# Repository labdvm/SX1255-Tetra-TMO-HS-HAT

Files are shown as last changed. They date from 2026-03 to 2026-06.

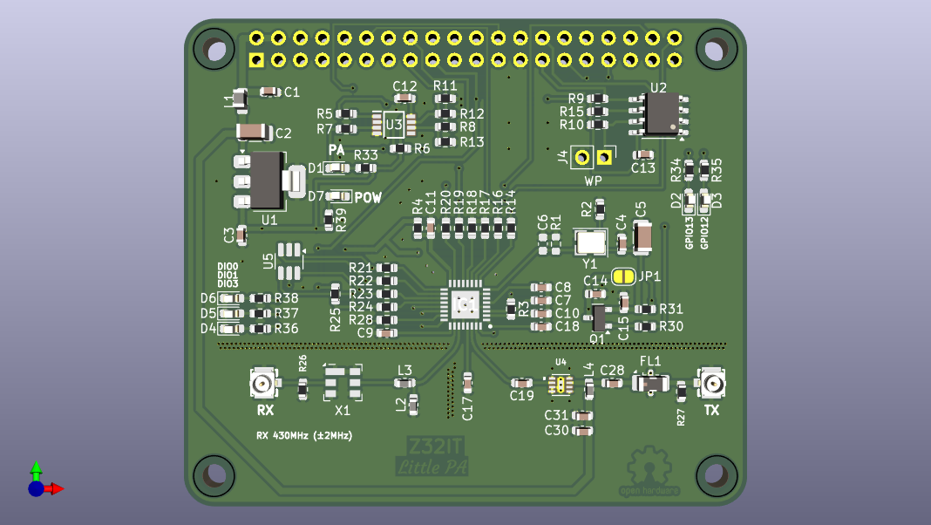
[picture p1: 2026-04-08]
HAT with PA/HAT with PA.png

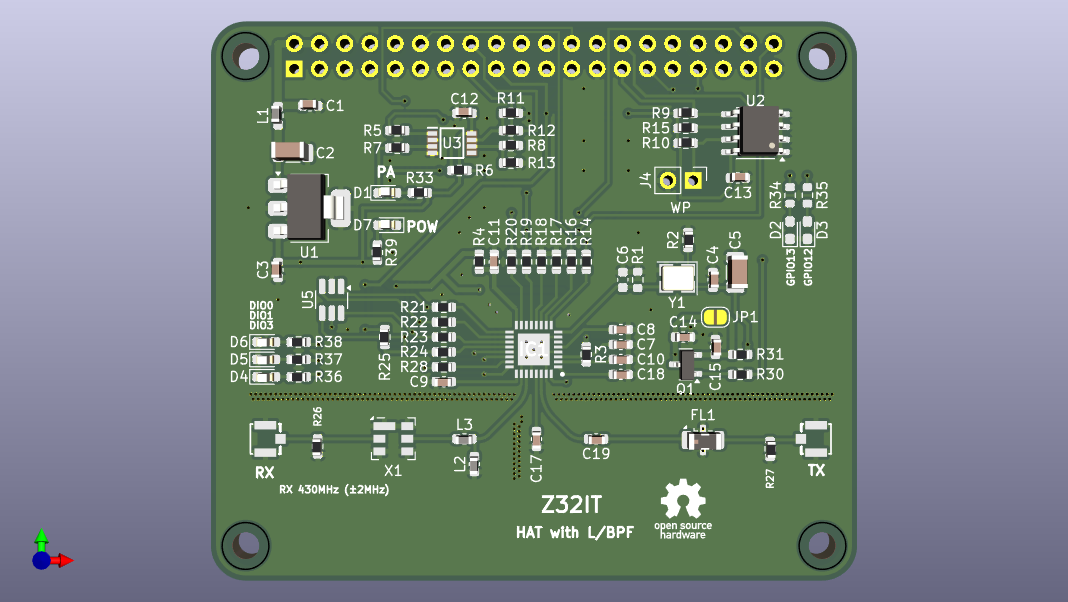
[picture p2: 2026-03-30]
HAT without PA/HAT without PA.png

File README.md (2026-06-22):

# SX1255--HAT's

# Little PA HAT you can order from here:
- <a href="https://www.pcbway.com/project/shareproject/SX1255_HAT_Little_PA_16c1f7b7.html">PCB from PCBWay</a>

This is modified SXceiver, thanks to Tatu Peltola for shared schematic.
# Two versions of HAT's: HAT with (LPF_TX, BPF_RX filters and PA) and HAT with (LPF_TX, BPF_RX filters without PA) and added SPI line protection IC. The first HAT also is known as "Little PA".
# The PA (TQP3M9036) can amplify up to ~25dBm @ (70cm-band) 
# I can make Custom design too. (pclab.mk@gmail.com)
# RPi 4/5, fast-write micro-sd card or upgraded with M.2 nvme drive.
# The eeprom is for HW-ID " https://github.com/tejeez/sxxcvr/blob/main/dts/README.md ".
# For Tetra-TMO Base Station this is the installing procedures, " https://github.com/MidnightBlueLabs/tetra-bluestation-docs/wiki ".
# BlueStation, https://github.com/MidnightBlueLabs/tetra-bluestation
# BlueStation Tetra TMO configurator " https://bluestation.russel053.com/ "
# FlowStation, https://github.com/razvanzeces/flowstation
# Nexus-BS, https://github.com/invictus737/nexus-bs

Install FlowStation ---for sxceiver---
# 1. Install Trixie 64bit-LITE
2. Install lib's:
# sudo apt update
# sudo apt install git make g++ cmake
# sudo apt install libsoapysdr-dev
# sudo apt install soapysdr-tools
# sudo apt install libasound2-dev
# sudo apt install clang llvm-dev libclang-dev

3. Install Rust:
# curl https://sh.rustup.rs -sSf | sh

4. RPi-setup:
"enable SPI and I2C"
# sudo raspi-config > Interface Options > "enable and reboot the rpi"
# sudo nano /boot/firmware/config.txt
"add"
# dtparam=i2c_vc=on
"Reboot the Rpi"

5. Install SoapySX:
# cd
# git clone "https://github.com/tejeez/sxxcvr.git"
# cd sxxcvr/SoapySX
# mkdir build
# cd build
# cmake ..
# make
# sudo make install
# sudo ldconfig

Check that the driver is available:
# SoapySDRUtil --info

Check that the device is detected:
# ls -l /proc/device-tree/hat
# SoapySDRUtil --probe=driver=sx

6. Install The FlowStation:
# git clone https://github.com/razvanzeces/flowstation
# cd flowstation
# . "$HOME/.cargo/env"
# cargo build --release (or cargo build --release -j1)
# cp example_config/config.toml config.toml
# nano config.toml "configure the base station"
- After configured "config.toml" make a fallback copy
# cp config.toml config.toml.fallback

7. Run:
# cd flowstation
# ./target/release/bluestation-bs ./config.toml

8. Update:
# git pull
# cargo build --release

# Z32IT

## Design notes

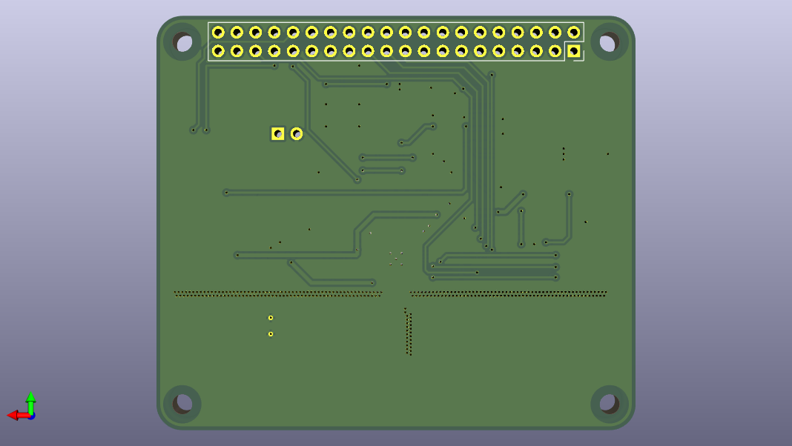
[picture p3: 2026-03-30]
HAT without PA/HAT without PA_b.png

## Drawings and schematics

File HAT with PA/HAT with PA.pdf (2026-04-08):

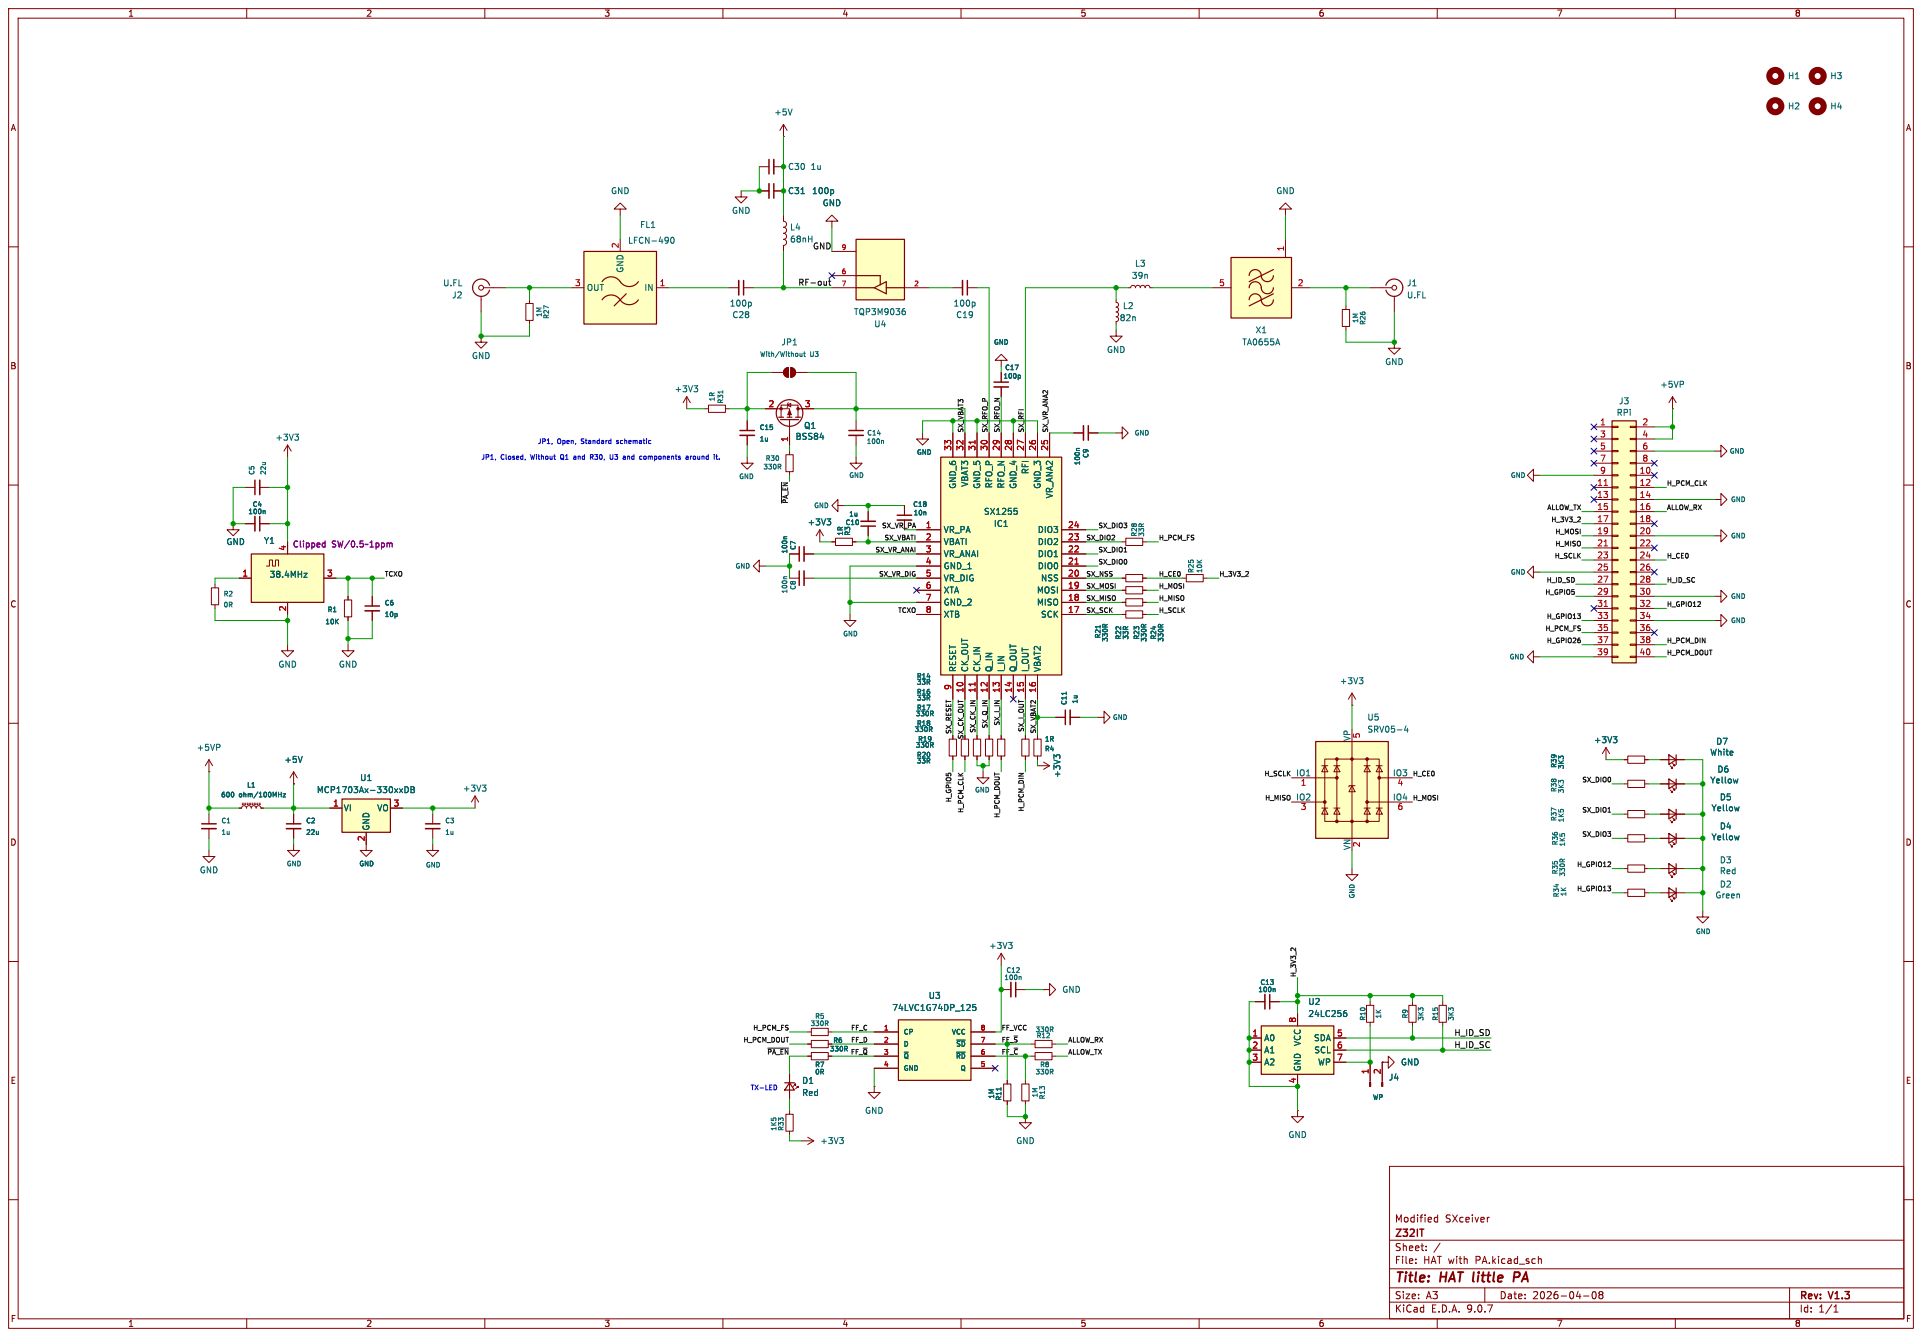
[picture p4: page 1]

9 VBAT3 32 CK_OUT 10 GND_5 31 CK_IN 11 RFO_P 30 Q_IN 12 RFO_N 29 I_IN 13 GND_4 28 Q_OUT 14 RFI 27 I_OUT 15 GND_3 26 VBAT2 16 VR_ANA2 25 DIO3 24 DIO2 23 DIO1 22 DIO0 21 NSS 20 MOSI 19 MISO 18 SCK 17

Id: 1/1 Title: HAT little PA

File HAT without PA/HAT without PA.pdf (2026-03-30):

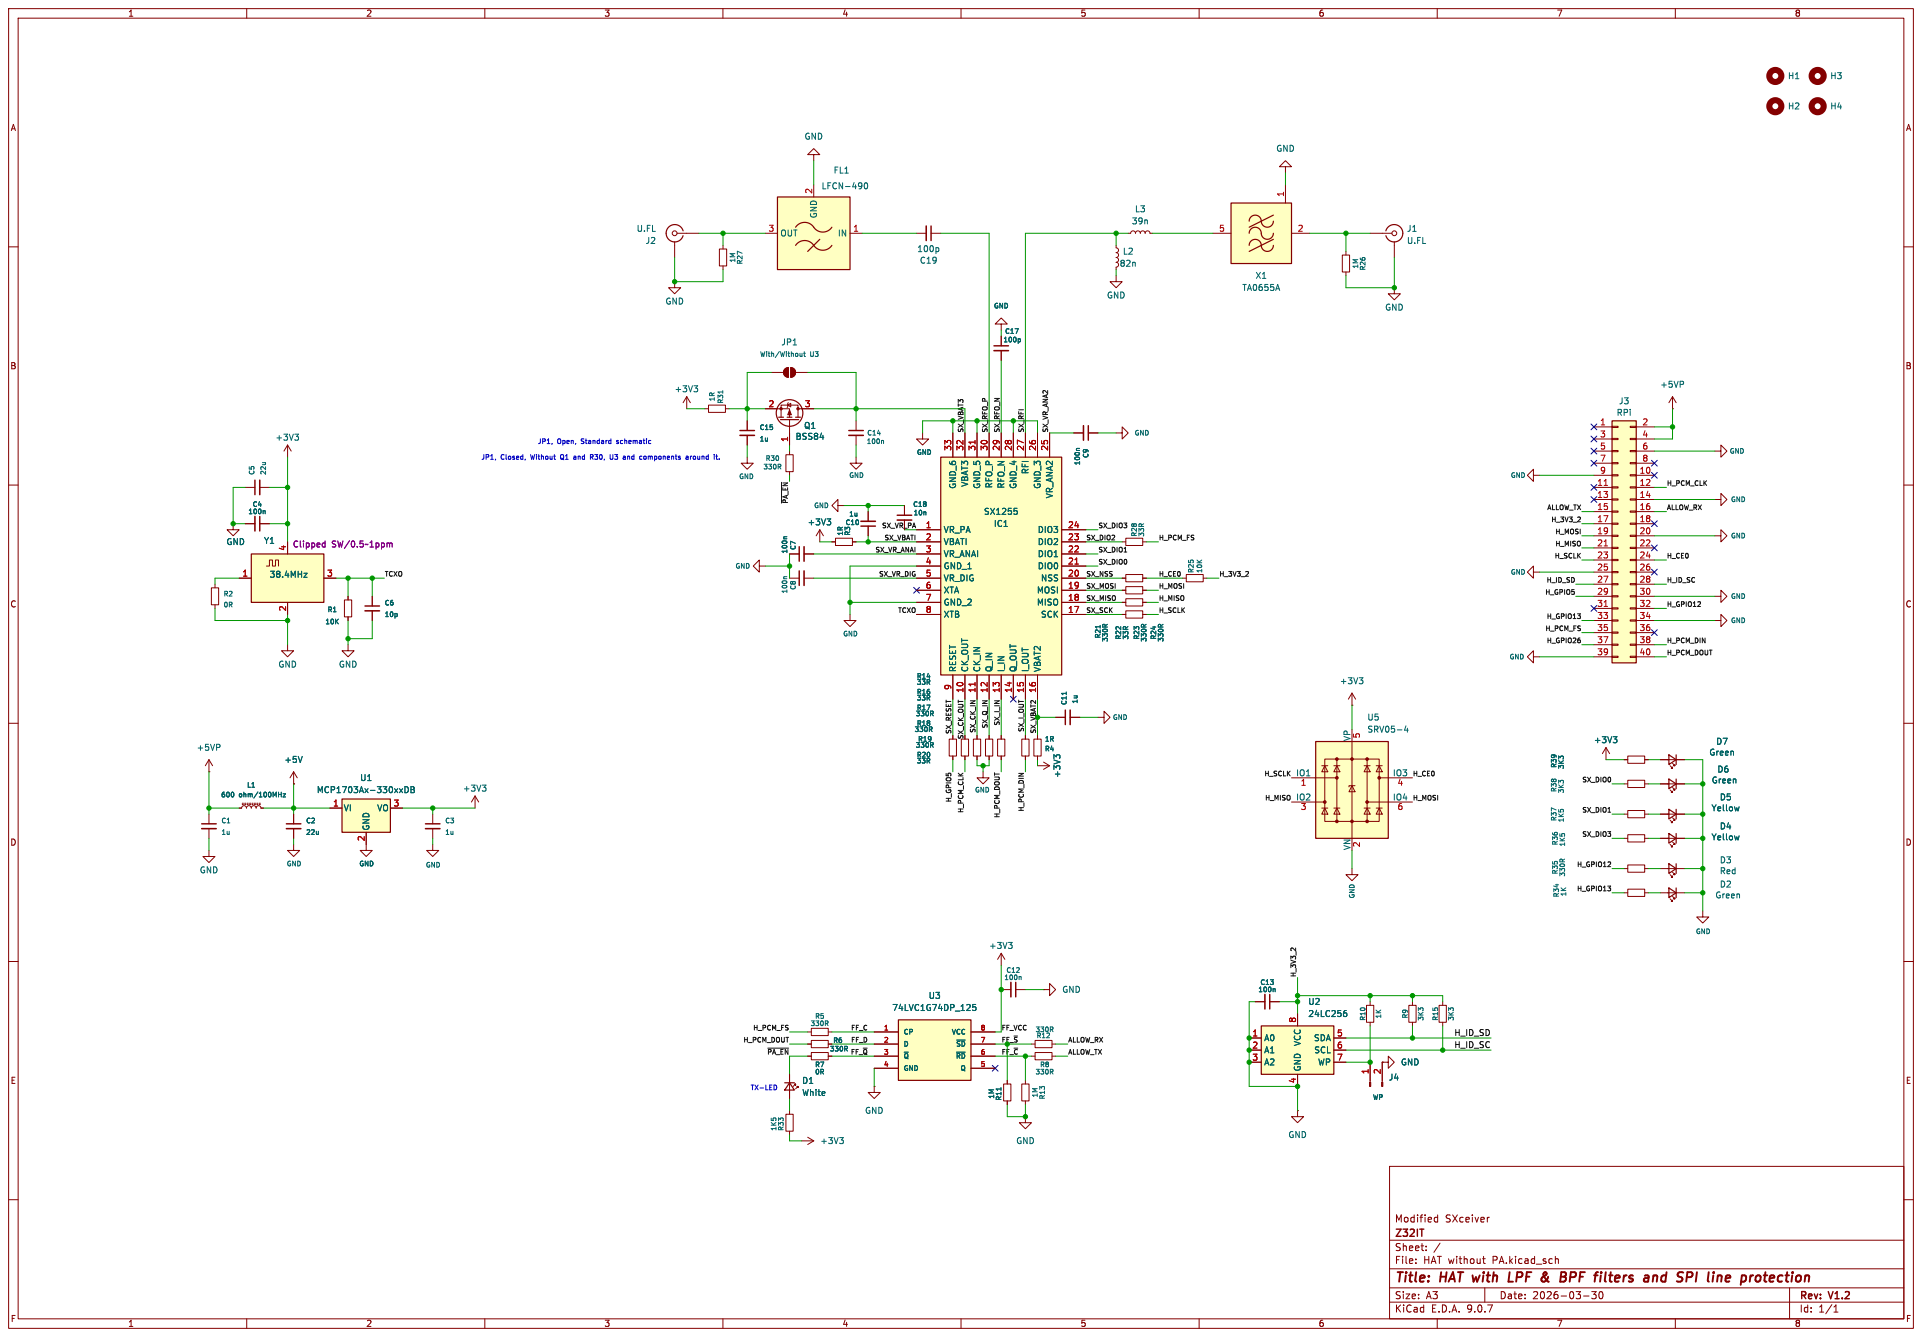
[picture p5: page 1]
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

9 VBAT3 32 CK_OUT 10 GND_5 31 CK_IN 11 RFO_P 30 Q_IN 12 RFO_N 29 I_IN 13 GND_4 28 Q_OUT 14 RFI 27 I_OUT 15 GND_3 26 VBAT2 16 VR_ANA2 25 DIO3 24 DIO2 23 DIO1 22 DIO0 21 NSS 20 MOSI 19 MISO 18 SCK 17 C9 100n

Id: 1/1 Title: HAT with LPF & BPF filters and SPI line protection

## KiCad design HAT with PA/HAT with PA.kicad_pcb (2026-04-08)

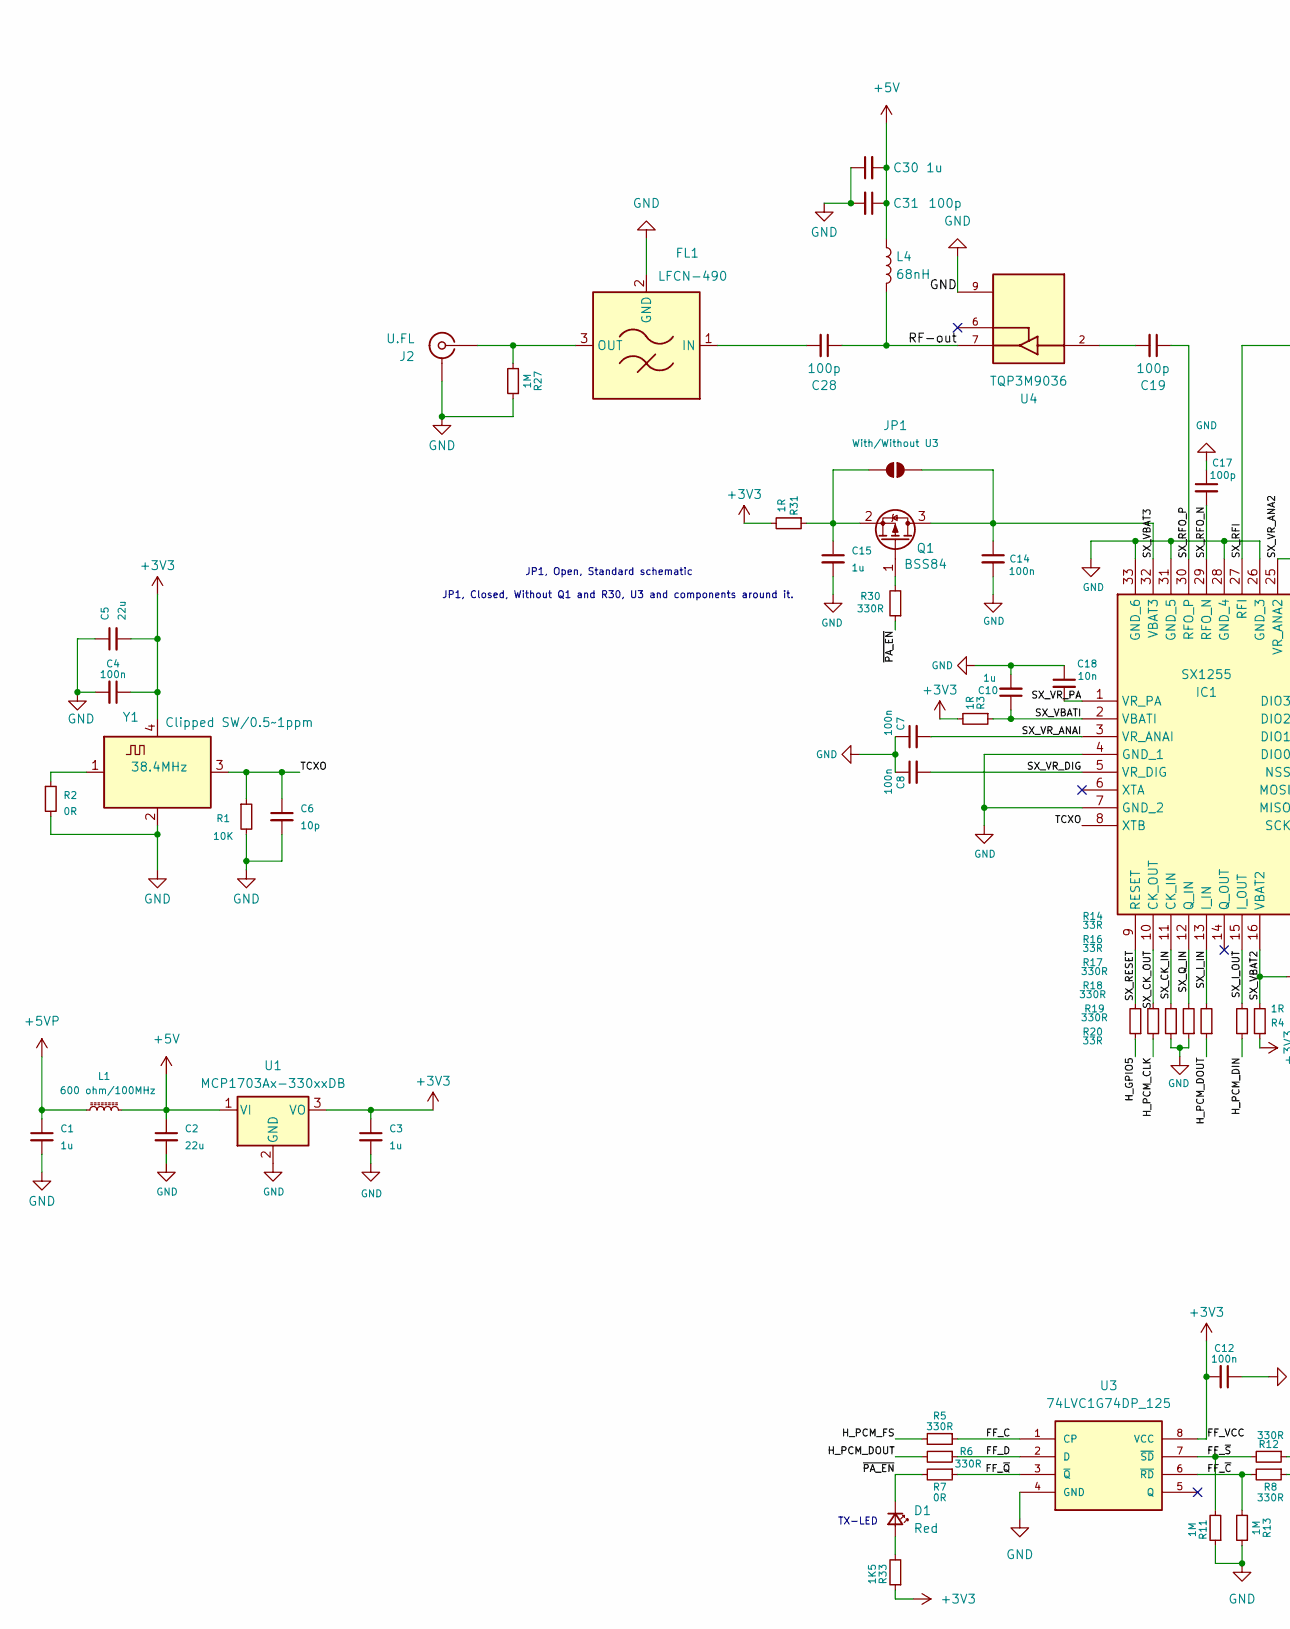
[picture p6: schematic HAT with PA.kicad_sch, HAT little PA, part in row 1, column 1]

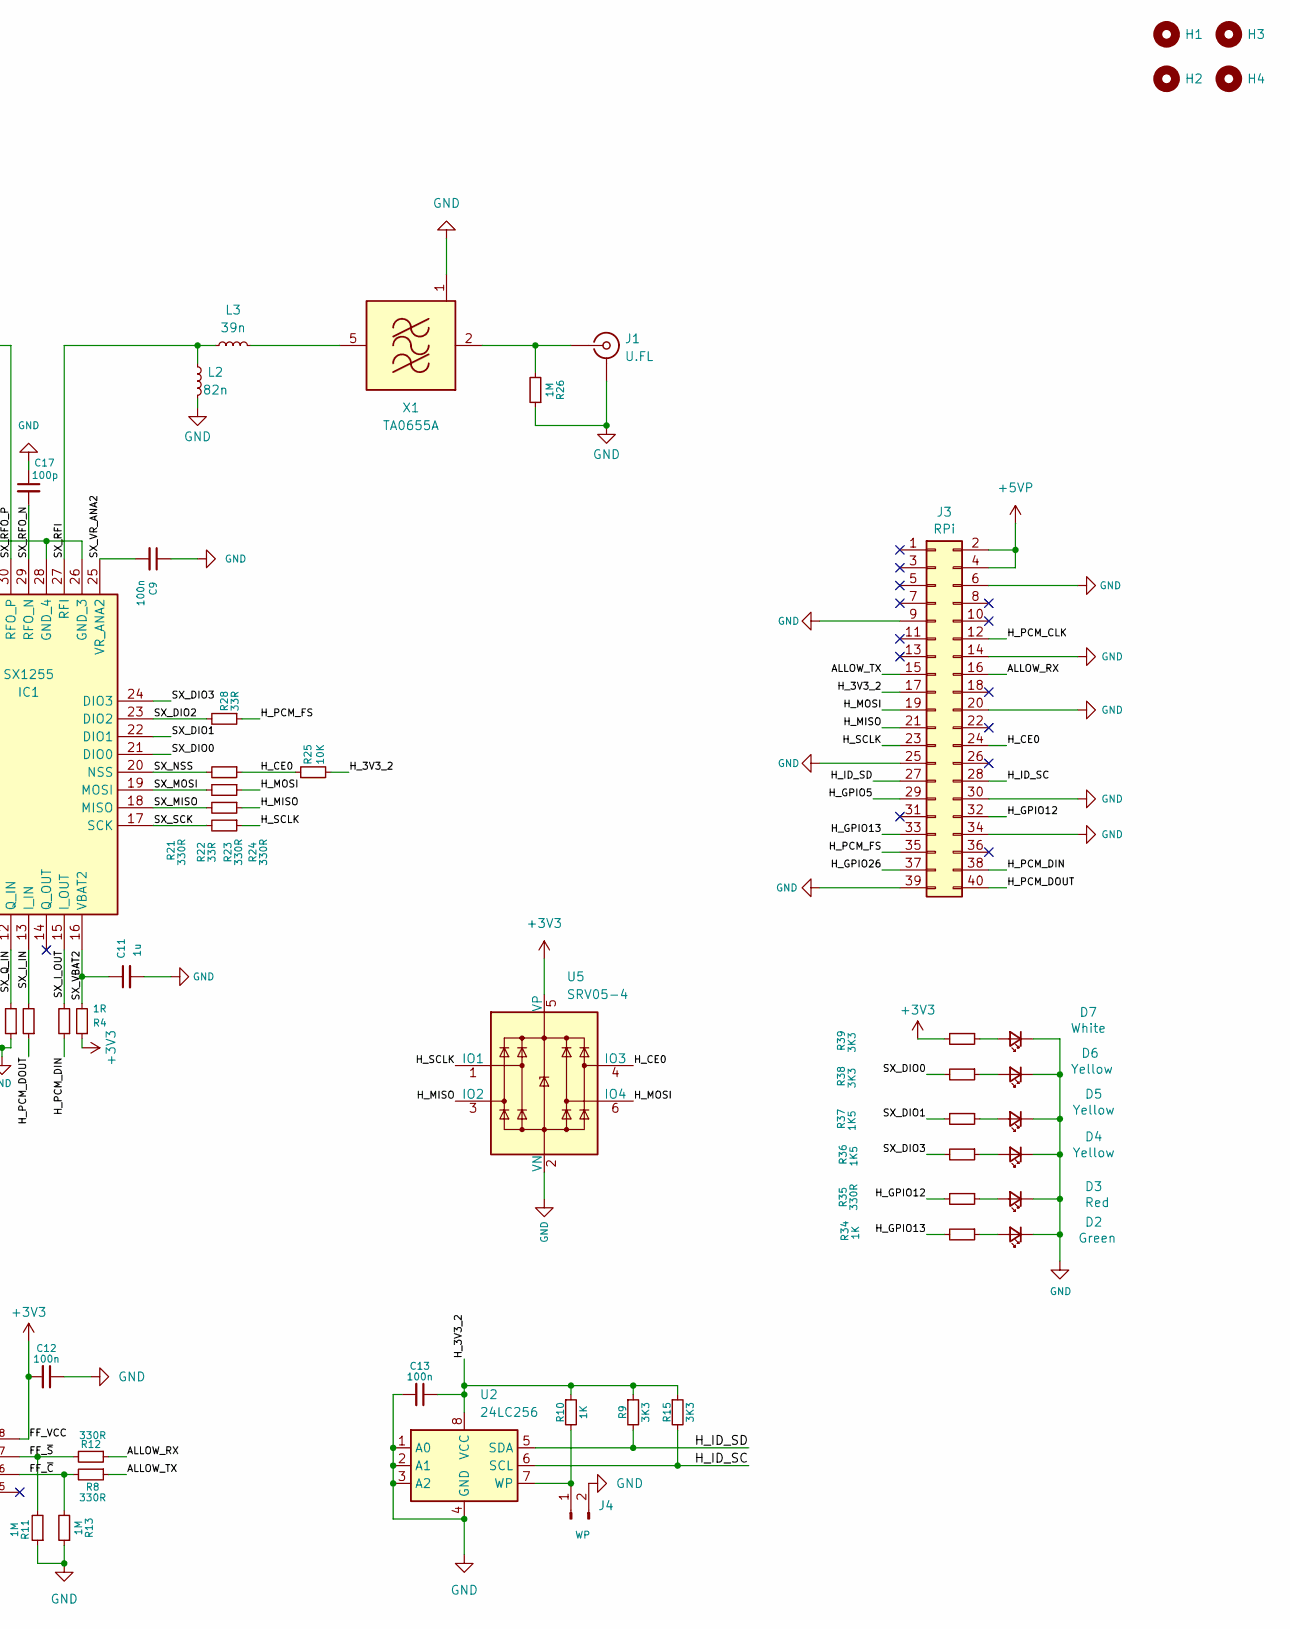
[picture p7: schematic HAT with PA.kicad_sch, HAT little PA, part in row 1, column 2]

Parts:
C1, C3, C10, C11, C15, C30: 1u; C_0603_1608Metric; Part Number 311-3484-1-ND
C2, C5: 22u; C_1206_3216Metric; Part Number 1276-3148-1-ND
C4, C7, C8, C9, C12, C13, C14: 100n; C_0603_1608Metric; Part Number 720-1688-1-ND
C6: 10p; C_0603_1608Metric; Part Number 399-14932-1-ND
C17, C19, C28, C31: 100p; C_0603_1608Metric; Part Number 399-15348-1-ND
C18: 10n; C_0603_1608Metric; Part Number 399-C0603C103K8RACTUCT-ND
D1, D3: Red; LED_0603_1608Metric_Pad1.05x0.95mm_HandSolder; Part Number 160-1479-1-ND
D2: Green; LED_0603_1608Metric_Pad1.05x0.95mm_HandSolder; Part Number 754-APT1608SGD3CT-ND
D4, D5, D6: Yellow; LED_0603_1608Metric_Pad1.05x0.95mm_HandSolder; Part Number 160-1437-1-ND
D7: White; LED_0603_1608Metric_Pad1.05x0.95mm_HandSolder; Part Number 160-LTST-T180UWETCT-ND
FL1: LFCN-490; Filter_Mini-Circuits_FV1206; Part Number 3157-LFCN-490+CT-ND
H1, H2, H3, H4: MountingHole; MountingHole_2.7mm_M2.5_DIN965
IC1: SX1255; QFN50P500X500X80-33N-D; Part Number SX1255IWLTRTCT-ND
J1, J2: U.FL; Part Number 343-CONMHF1-SMD-G-TCT-ND
J3: RPi; PinSocket_2x20_P2.54mm_Vertical
J4: WP; PinHeader_1x02_P2.54mm_Vertical
JP1: With/Without U3; SolderJumper-2_P1.3mm_Open_RoundedPad1.0x1.5mm
L1: 600 ohm/100MHz; L_0805_2012Metric; Part Number 490-1046-1-ND
L2: 82n; L_0603_1608Metric; Part Number 712-LRC0603CJ82NGV001TCT-ND
L3: 39n; L_0603_1608Metric; Part Number 712-LRC0603CJ39NGV001TCT-ND
L4: 68nH; L_0603_1608Metric; Part Number 712-LRC0603CJ68NGV001TCT-ND
Q1: BSS84; SOT-23; Part Number 3372-BSS84TR-ND
R1, R25: 10K; R_0603_1608Metric; Part Number 541-10.0KHCT-ND
R2, R7: 0R; R_0603_1608Metric; Part Number 541-0.0GCT-ND
R3, R4, R31: 1R; R_0603_1608Metric; Part Number 541-1.00HHCT-ND
R5, R6, R8, R12, R17, R18, R19, R21, R23, R24, R30, R35: 330R; R_0603_1608Metric; Part Number 541-330HCT-ND
R9, R15, R38, R39: 3K3; R_0603_1608Metric; Part Number 541-3.30KHCT-ND
R10, R34: 1K; R_0603_1608Metric; Part Number 541-1.00KHCT-ND
R11, R13, R26, R27: 1M; R_0603_1608Metric; Part Number 541-1.00MHCT-ND
R14, R16, R20, R22, R28: 33R; R_0603_1608Metric; Part Number 541-33.0HCT-ND
R33, R36, R37: 1K5; R_0603_1608Metric; Part Number 541-1.5KGCT-ND
U1: MCP1703Ax-330xxDB; SOT-223-3_TabPin2; Part Number MCP1703T-3302E/DBCT-ND
U2: 24LC256; SOIC-8_3.9x4.9mm_P1.27mm; Part Number 24LC256-I/SN-ND
U3: 74LVC1G74DP_125; SOP65P400X110-8N; Part Number 1727-5983-1-ND
U4: TQP3M9036; SON50P200X200X95-9N; Part Number 2312-TQP3M9036CT-ND
U5: SRV05-4; SOT-23-6_Handsoldering; DigiKey Part Number SRV05-4CT-ND
X1: TA0655A; Filter_SAW-6_3.8x3.8mm
Y1: 38.4MHz; Crystal_SMD_3225-4Pin_3.2x2.5mm; Part Number 114-TG2520SMN38.4000M-MCGNNM3CT-ND

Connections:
+3V3: C3.1, C4.1, C5.2, C12.2, R3.2, R4.1, R31.2, R33.1, R39.2, U1.3 (VO), U3.8 (VCC), U5.5 (VP), Y1.4 (VDD)
+5V: C2.1, C30.2, C31.1, L1.2, L4.1, U1.1 (VI)
+5VP: C1.1, J3.2, J3.4, L1.1
/ALLOW_RX: J3.16, R12.1
/ALLOW_TX: J3.15, R8.1
/FF_C: R5.1, U3.1 (CP)
/FF_D: R6.1, U3.2 (D)
/FF_~C: R8.2, R13.2, U3.6 (~RD)
/FF_~Q: R7.1, U3.3 (~Q)
/FF_~S: R11.2, R12.2, U3.7 (~SD)
/H_3V3_2: C13.1, J3.17, R9.1, R10.1, R15.1, R25.2, U2.8 (VCC)
/H_CE0: J3.24, R24.1, R25.1, U5.4 (IO3)
/H_GPIO5: J3.29, R14.1
/H_GPIO12: J3.32, R35.2
/H_GPIO13: J3.33, R34.2
/H_GPIO26: J3.37
/H_ID_SC: J3.28, R15.2, U2.6 (SCL)
/H_ID_SD: J3.27, R9.2, U2.5 (SDA)
/H_MISO: J3.21, R22.1, U5.3 (IO2)
/H_MOSI: J3.19, R23.1, U5.6 (IO4)
/H_PCM_CLK: J3.12, R16.1
/H_PCM_DIN: J3.38, R20.1
/H_PCM_DOUT: J3.40, R6.2, R19.1
/H_PCM_FS: J3.35, R5.2, R28.1
/H_SCLK: J3.23, R21.1, U5.1 (IO1)
/RF-out: C28.1, L4.2, U4.7
/SX_CK_IN: IC1.11 (CK_IN), R17.2
/SX_CK_OUT: IC1.10 (CK_OUT), R16.2
/SX_DIO0: IC1.21 (DIO0), R38.2
/SX_DIO1: IC1.22 (DIO1), R37.2
/SX_DIO2: IC1.23 (DIO2), R28.2
/SX_DIO3: IC1.24 (DIO3), R36.2
/SX_I_IN: IC1.13 (I_IN), R19.2
/SX_I_OUT: IC1.15 (I_OUT), R20.2
/SX_MISO: IC1.18 (MISO), R22.2
/SX_MOSI: IC1.19 (MOSI), R23.2
/SX_NSS: IC1.20 (NSS), R24.2
/SX_Q_IN: IC1.12 (Q_IN), R18.2
/SX_RESET: IC1.9 (RESET), R14.2
/SX_RFI: IC1.27 (RFI), L2.2, L3.2
/SX_RFO_N: C17.2, IC1.29 (RFO_N)
/SX_RFO_P: C19.1, IC1.30 (RFO_P)
/SX_SCK: IC1.17 (SCK), R21.2
/SX_VBAT2: C11.1, IC1.16 (VBAT2), R4.2
/SX_VBAT3: C14.1, IC1.32 (VBAT3), JP1.2 (B), Q1.3 (D)
/SX_VBATI: C10.1, IC1.2 (VBATI), R3.1
/SX_VR_ANA2: C9.2, IC1.25 (VR_ANA2)
/SX_VR_ANAI: C7.2, IC1.3 (VR_ANAI)
/SX_VR_DIG: C8.2, IC1.5 (VR_DIG)
/SX_VR_PA: C18.2, IC1.1 (VR_PA)
/TCXO: C6.1, IC1.8 (XTB), R1.1, Y1.3 (OUT)
/~PA_EN: D1.1 (K), R7.2, R30.1
GND: C1.2, C2.2, C3.2, C4.2, C5.1, C6.2, C7.1, C8.1, C9.1, C10.2, C11.2, C12.1, C13.2, C14.2, C15.2, C17.1, C18.1, C30.1, C31.2, D2.1 (K), D3.1 (K), D4.1 (K), D5.1 (K), D6.1 (K), D7.1 (K), FL1.2 (GND), FL1.4 (GND), IC1.4 (GND_1), IC1.7 (GND_2), IC1.26 (GND_3), IC1.28 (GND_4), IC1.31 (GND_5), IC1.33 (GND_6), J1.2 (Ext), J2.2 (Ext), J3.6, J3.9, J3.14, J3.20, J3.25, J3.30, J3.34, J3.39, J4.2, L2.1, R1.2, R2.2, R11.1, R13.1, R17.1, R18.1, R26.1, R27.1, U1.2 (GND), U2.1 (A0), U2.2 (A1), U2.3 (A2), U2.4 (GND), U3.4 (GND), U4.1, U4.3, U4.4, U4.5, U4.8, U4.9, U4.V1, U4.V2, U4.V3, U5.2 (VN), X1.1 (GND), X1.3 (GND), X1.4 (GND), X1.6 (GND), Y1.2 (GND)
unnamed: C19.2, U4.2
unnamed: D1.2 (A), R33.2
unnamed: D2.2 (A), R34.1
unnamed: D3.2 (A), R35.1
unnamed: D4.2 (A), R36.1
unnamed: D5.2 (A), R37.1
unnamed: D6.2 (A), R38.1
unnamed: D7.2 (A), R39.1
unnamed: C28.2, FL1.1 (IN)
unnamed: FL1.3 (OUT), J2.1 (In), R27.2
unnamed: J1.1 (In), R26.2, X1.2 (IN)
unnamed: J4.1, R10.2, U2.7 (WP)
unnamed: C15.1, JP1.1 (A), Q1.2 (S), R31.1
unnamed: Q1.1 (G), R30.2
unnamed: L3.1, X1.5 (OUT)
unnamed: R2.1, Y1.1 (Tri-State)

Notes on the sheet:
JP1, Closed, Without Q1 and R30, U3 and components around it.
JP1, Open, Standard schematic
TX-LED

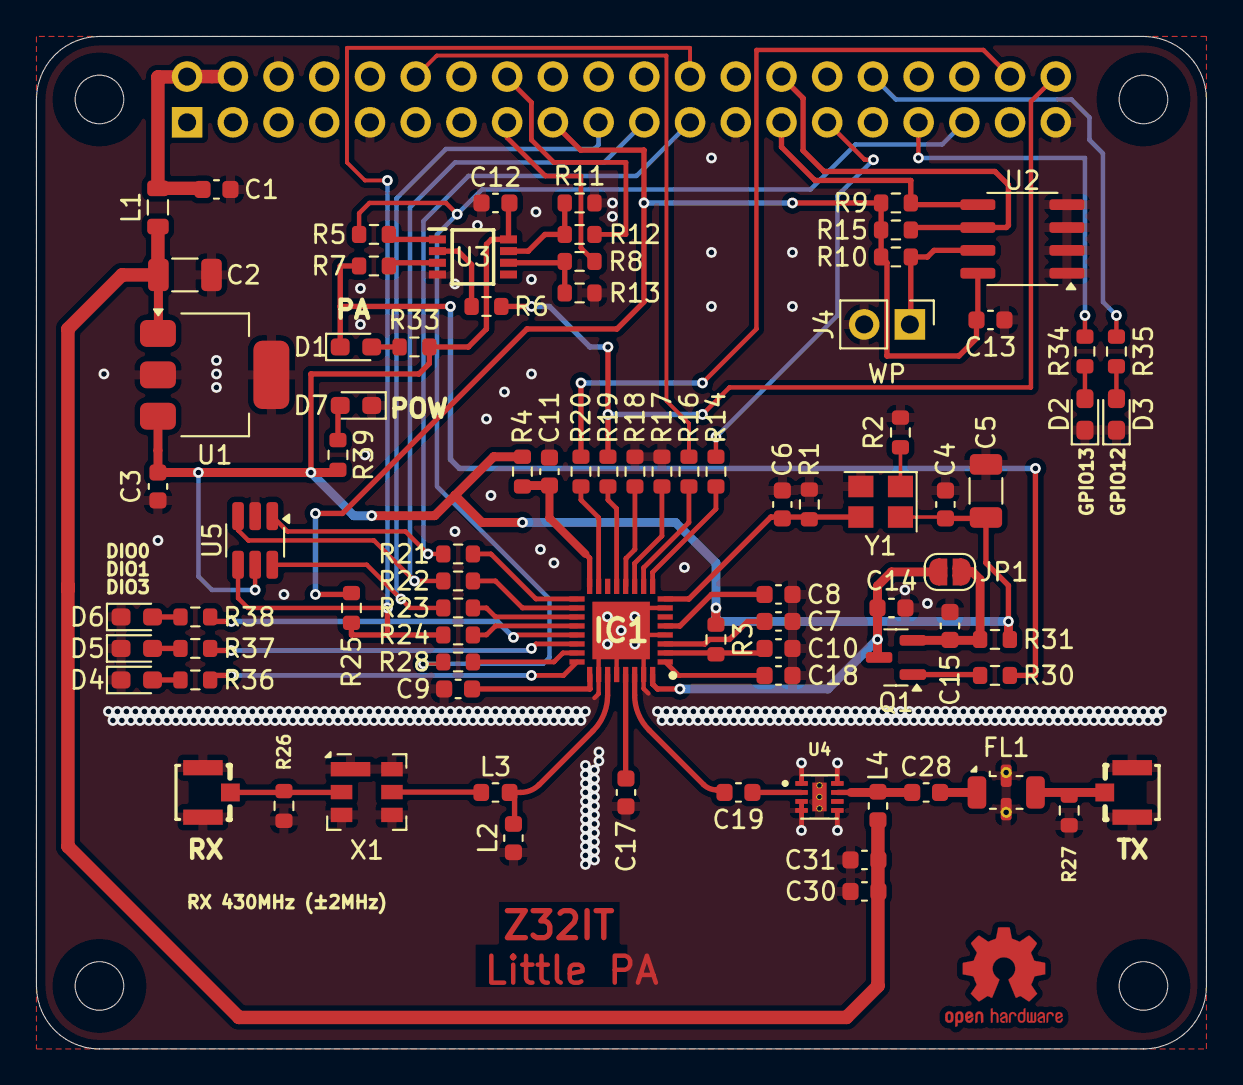
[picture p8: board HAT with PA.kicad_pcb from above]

Board: 2 copper layers, 65.0 x 56.2 mm, 88 parts (1 on the bottom side), 68 nets.

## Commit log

2026-03-30 Update filter types in README for HAT versions
2026-05-12 Update README with FlowStation installation steps
    Added installation instructions for FlowStation and related dependencies.
2026-06-17 Update Raspberry Pi version in README
2026-06-18 Update README with ordering information for Little PA HAT
    Added a link to order the Little PA HAT from PCBWay.
